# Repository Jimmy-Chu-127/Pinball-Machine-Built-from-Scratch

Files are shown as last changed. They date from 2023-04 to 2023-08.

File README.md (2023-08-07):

# Pinball Machine Built from Scratch

<!-- PROJECT LOGO -->
<br />
<div align="center">
  <a href="https://github.com/othneildrew/Best-README-Template">
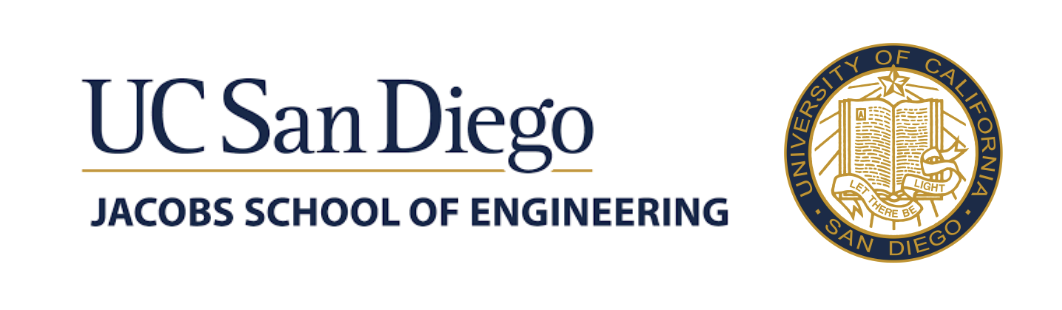
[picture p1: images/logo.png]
    
  </a>
  <h3 align="center">Pinball Machine Built from Scratch<br></h3>   
  <p align="center">
    Haozhang Chu, Yichen Yang <br>
  </p>
</div>

<!-- TABLE OF CONTENTS -->
<details>
  <summary><h2><b>Abstract</b><h2></summary>
    <li><a href="#finite-state-machine-design">Finite State Machine (FSM) Design</a></li>
    <li><a href="#whole-cad-assembly-view">Whole CAD Assembly View</a></li>
    <li><a href="#circuit-design">Circuit Design</a></li>
    <li><a href="#complete-physical-assembly">Complete Physical Assembly</a></li>
    <li>
      <a href="#subsystem-level-design">Subsystem Level Design</a>
      <ul>
        <li><a href="#ir-subsystem">IR subsystem</a></li>
        <li><a href="#flipper-subsystem">Flipper subsystem</a></li>
        <li><a href="#spinning-wheel-subsystem">Spinning wheel subsystem</a></li>
        <li><a href="#slingshot-subsystem">Slingshot subsystem</a></li>
      </ul>
    </li>
</details>

## Finite State Machine Design
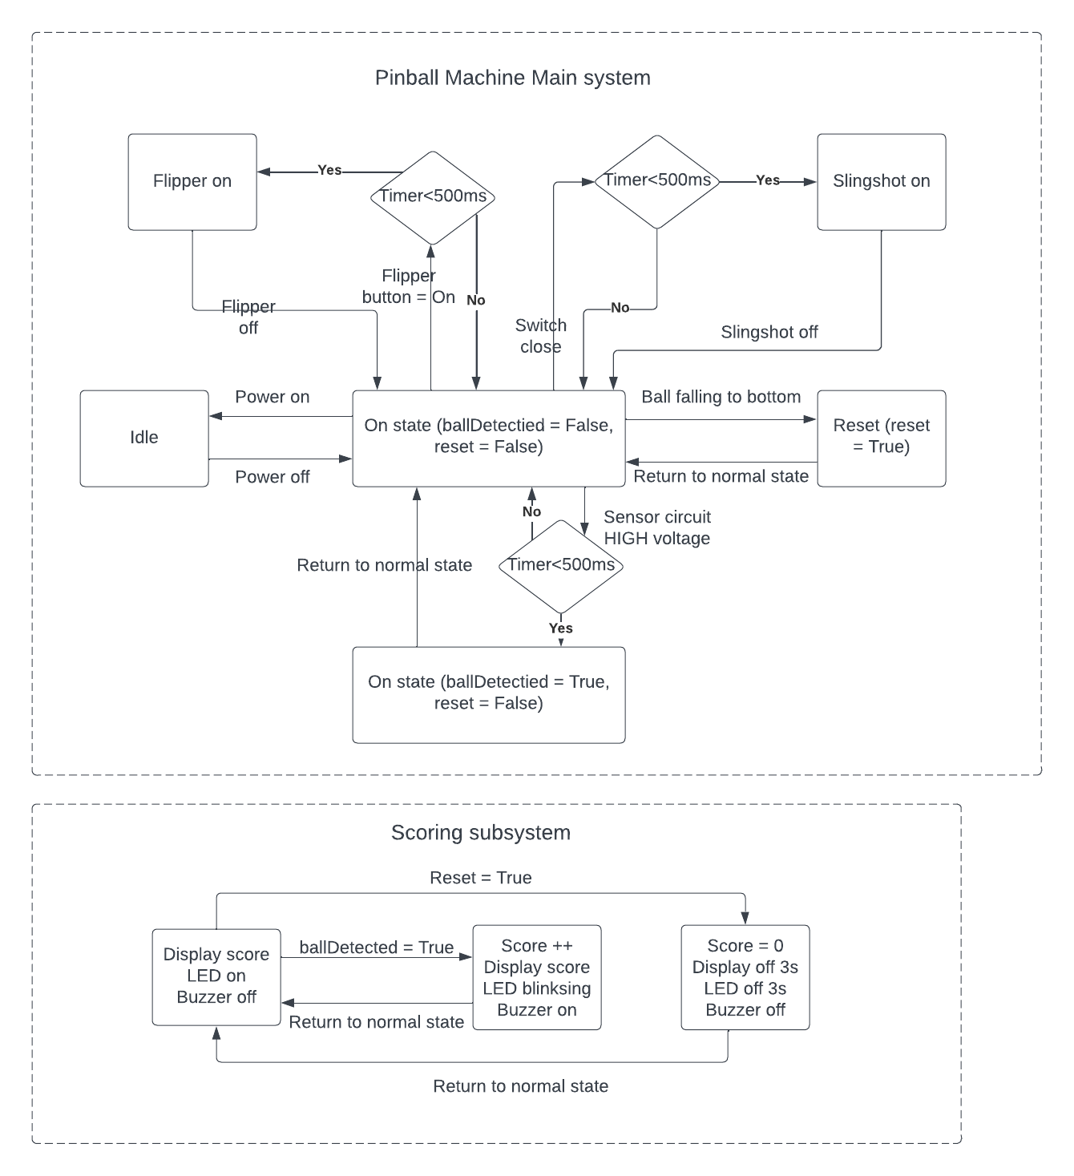
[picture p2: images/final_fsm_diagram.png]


## Whole CAD Assembly View
| Top view | Bottom View | Isometric view |
|:---:|:---:|:---:|
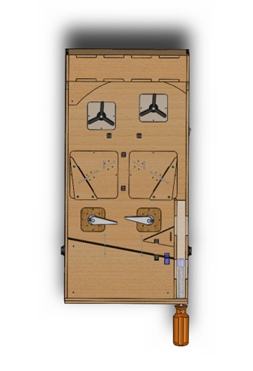
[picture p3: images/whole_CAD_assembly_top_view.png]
top view
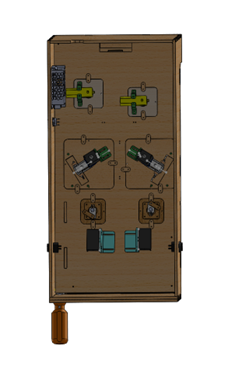
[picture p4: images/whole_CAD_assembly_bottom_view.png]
bottom view
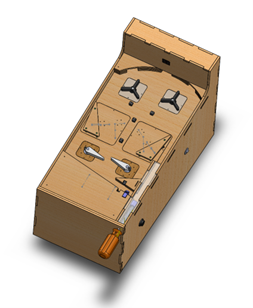
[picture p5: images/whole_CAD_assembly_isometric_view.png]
isometric view
|  |  |  |

## Circuit Design
| | |
|---|---|
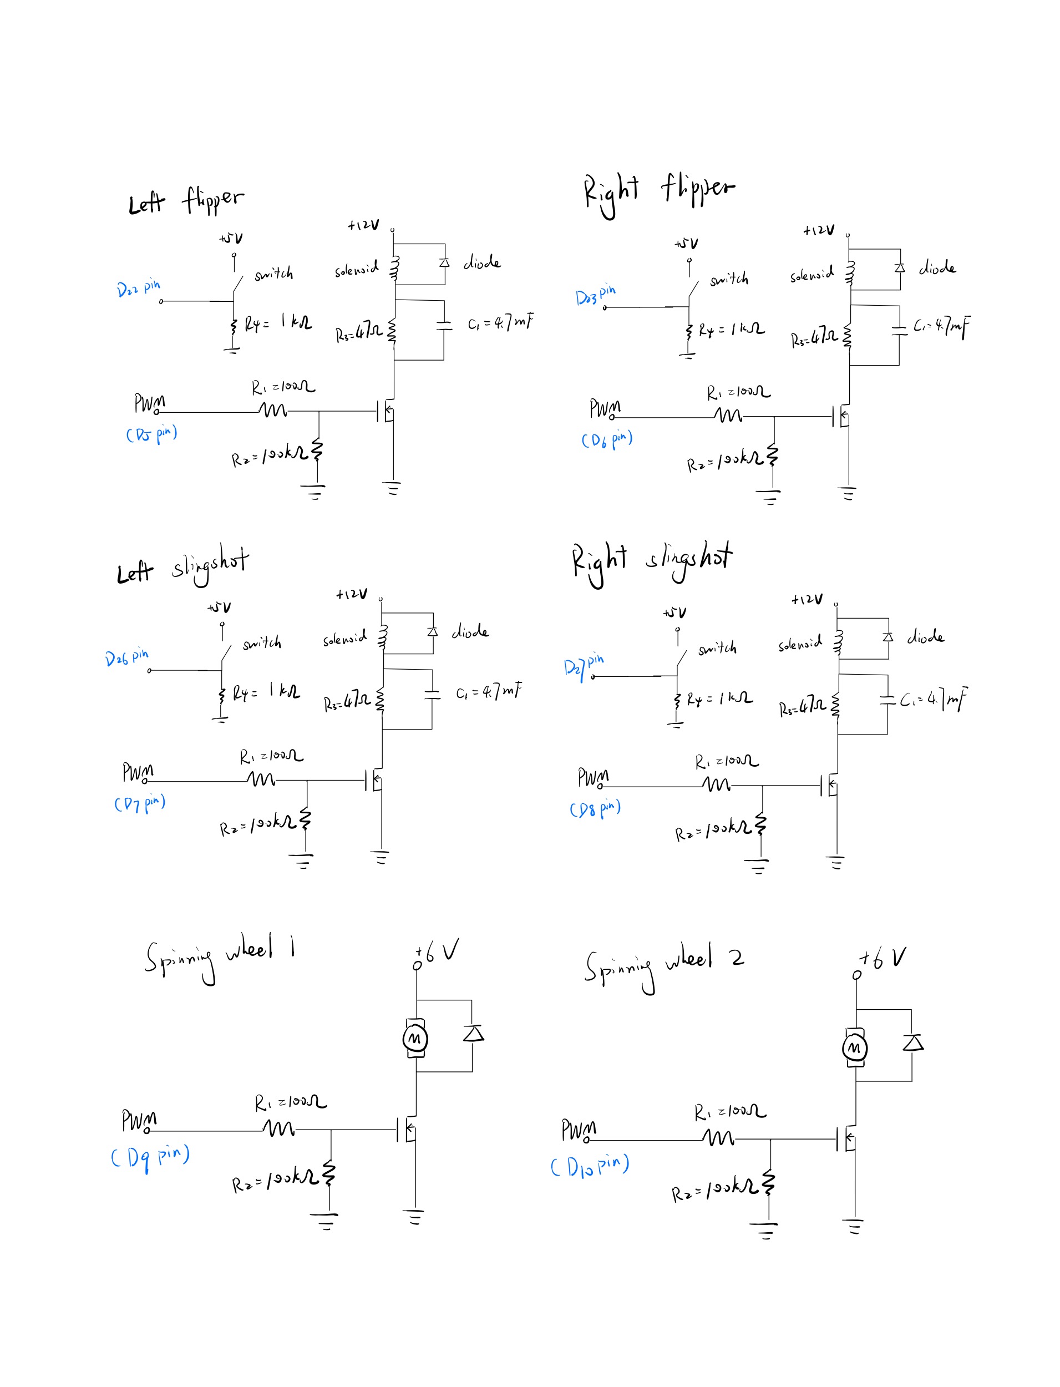
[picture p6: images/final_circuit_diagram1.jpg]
circuit1
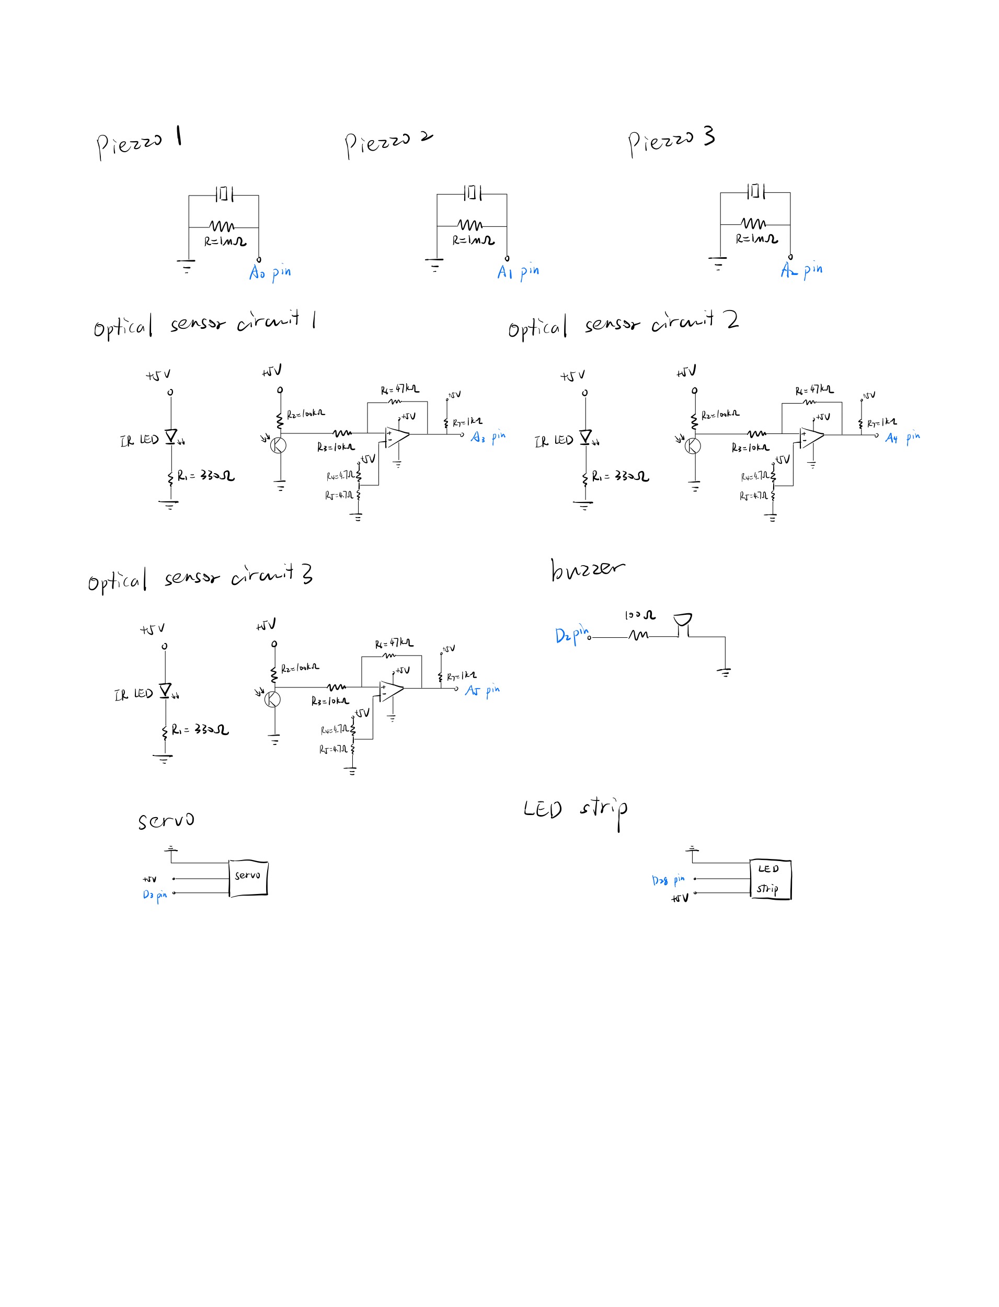
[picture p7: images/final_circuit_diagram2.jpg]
circuit1
|  |  |

## Complete Physical Assembly
| Top view | Bottom View | Isometric view |
|:---:|:---:|:---:|
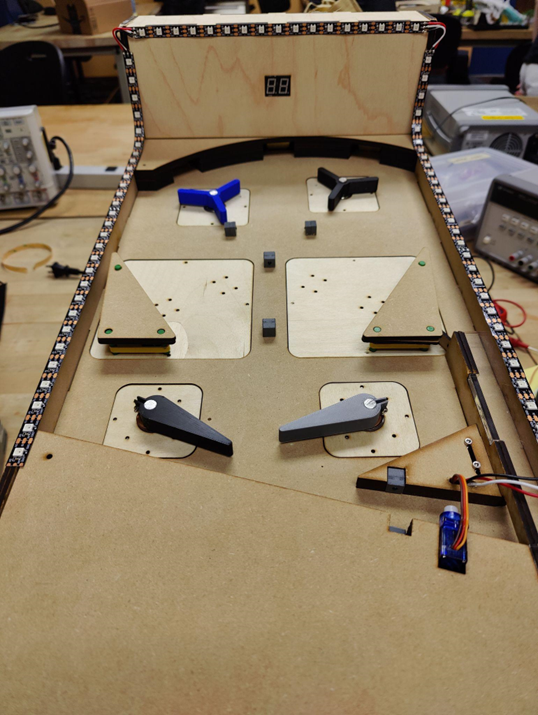
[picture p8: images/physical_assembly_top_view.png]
top view
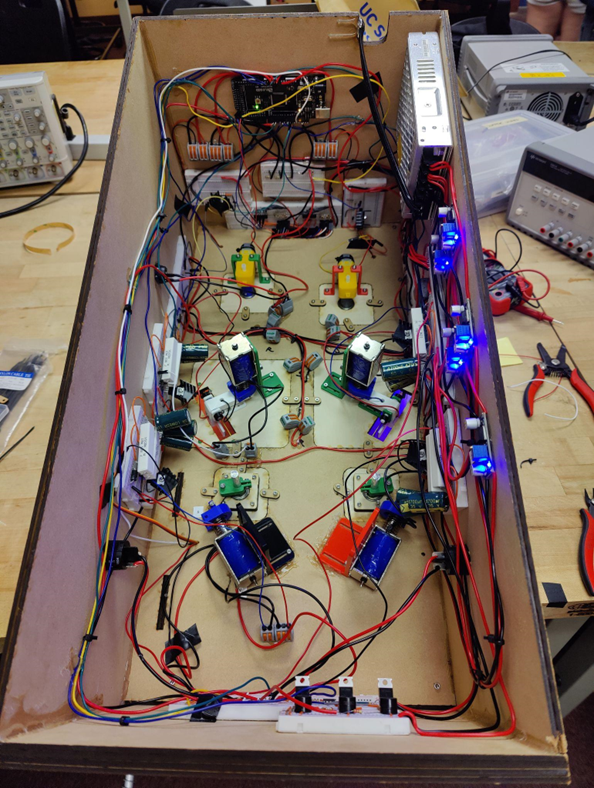
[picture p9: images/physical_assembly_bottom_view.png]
bottom view
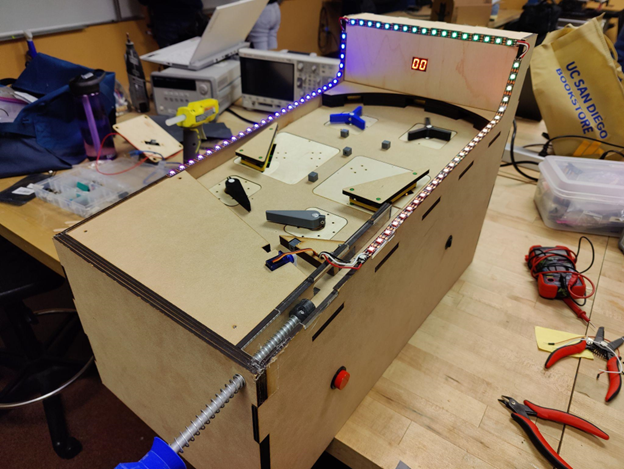
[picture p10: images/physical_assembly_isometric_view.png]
isometric view
|  |  |  |

## Subsystem Level Design

### IR subsystem
| Block Diagram | Circuit Diagram |
|:---:|:---:|
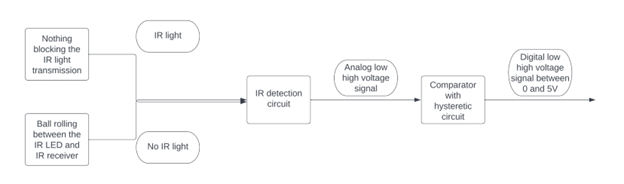
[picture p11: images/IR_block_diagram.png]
block diagram
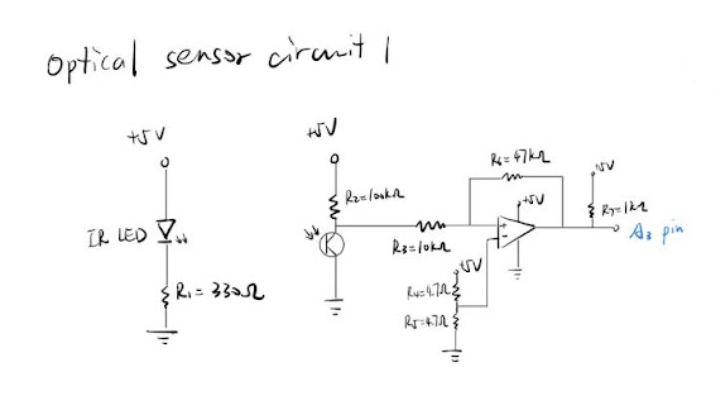
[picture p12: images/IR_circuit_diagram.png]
circuit diagram
|  |    |
| CAD Picture | Physical Picture |
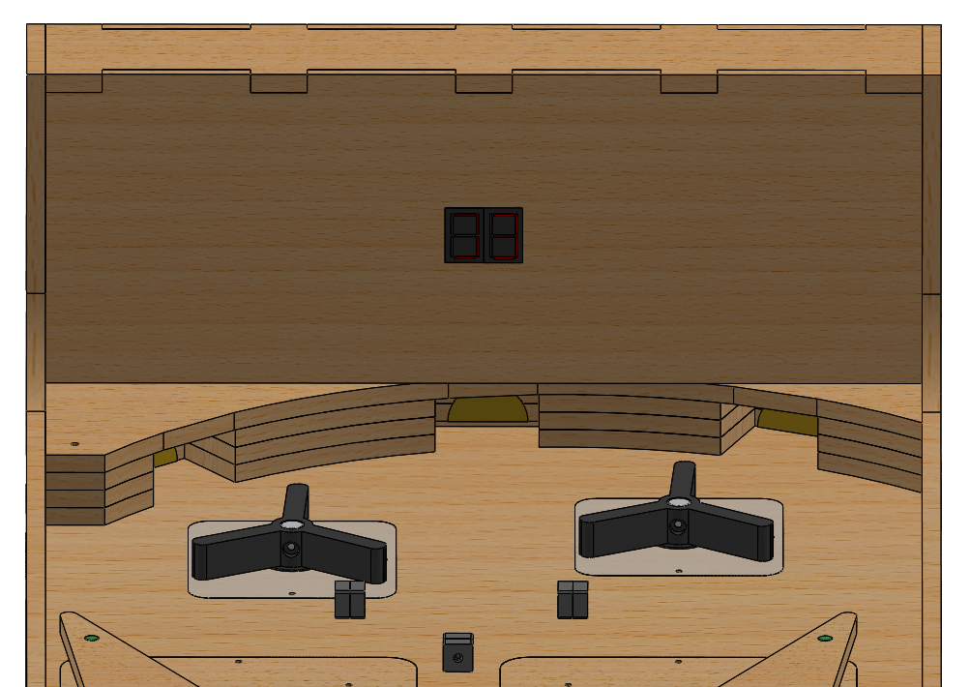
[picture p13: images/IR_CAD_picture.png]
CAD picture
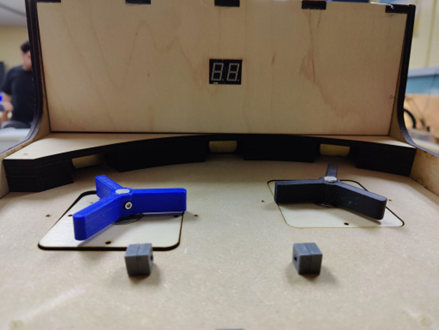
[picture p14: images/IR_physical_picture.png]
physical picture
|  |  |

### Flipper subsystem
| Block Diagram | Circuit Diagram |
|:---:|:---:|
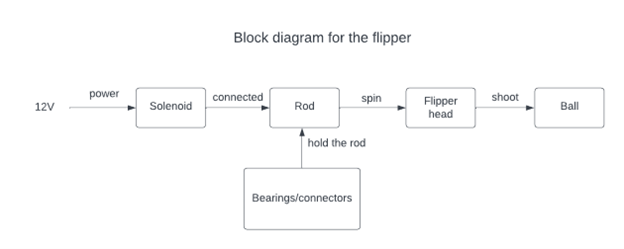
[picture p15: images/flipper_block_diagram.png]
block diagram
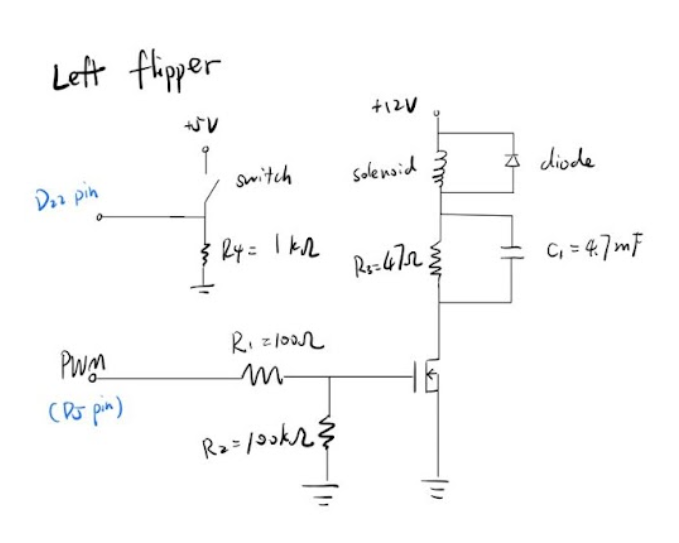
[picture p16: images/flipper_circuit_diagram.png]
circuit diagram
|  |    |
| CAD Picture | Physical Picture |
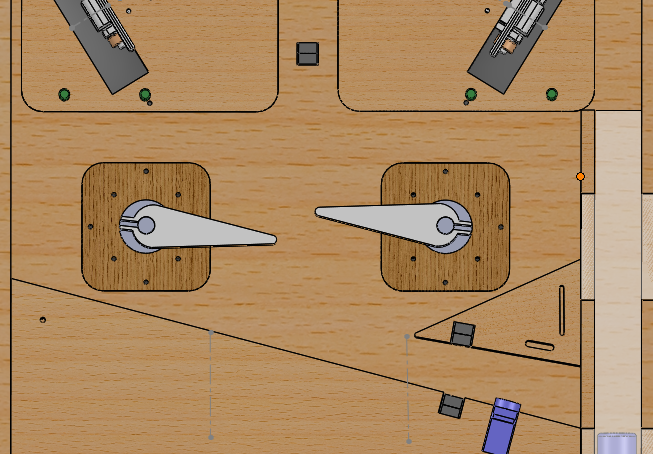
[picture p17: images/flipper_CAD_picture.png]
CAD picture
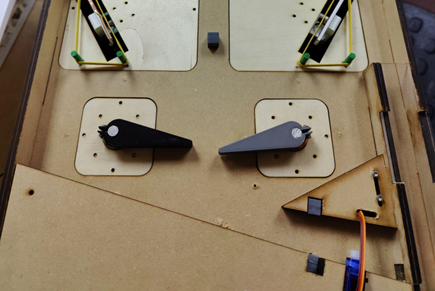
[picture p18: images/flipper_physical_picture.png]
physical picture
|  |  |

### Spinning wheel subsystem
| Block Diagram | Circuit Diagram |
|:---:|:---:|
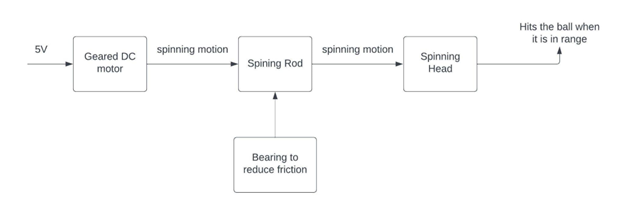
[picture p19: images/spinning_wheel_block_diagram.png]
block diagram
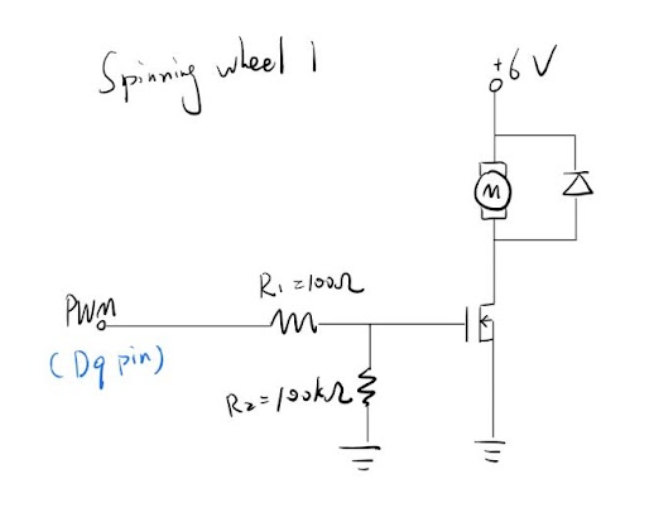
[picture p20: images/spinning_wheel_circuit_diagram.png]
circuit diagram
|  |    |
| CAD Picture | Physical Picture |
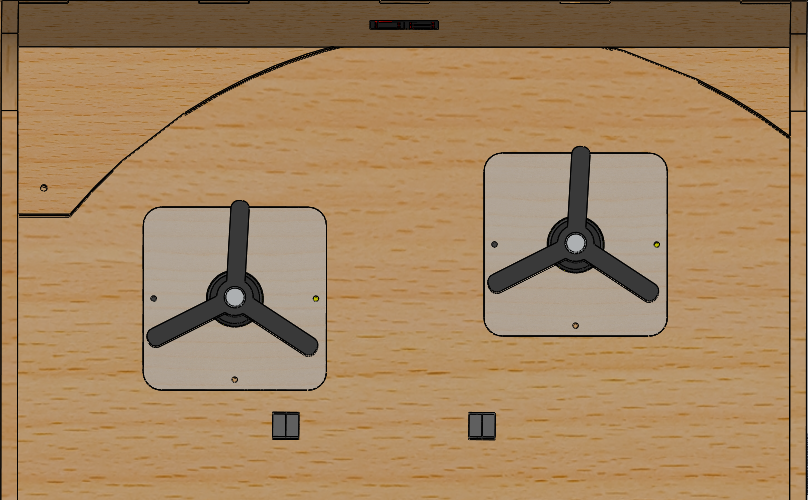
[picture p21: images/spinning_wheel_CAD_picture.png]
CAD picture
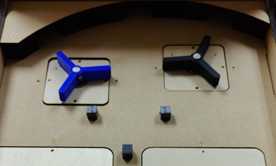
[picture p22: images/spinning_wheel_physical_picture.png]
physical picture
|  |  |

### Slingshot subsystem
| Block Diagram | Circuit Diagram |
|:---:|:---:|
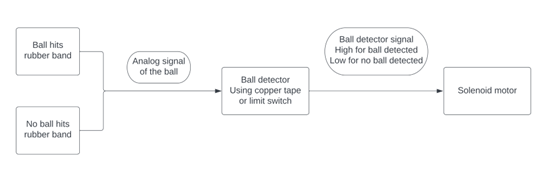
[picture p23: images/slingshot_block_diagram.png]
block diagram
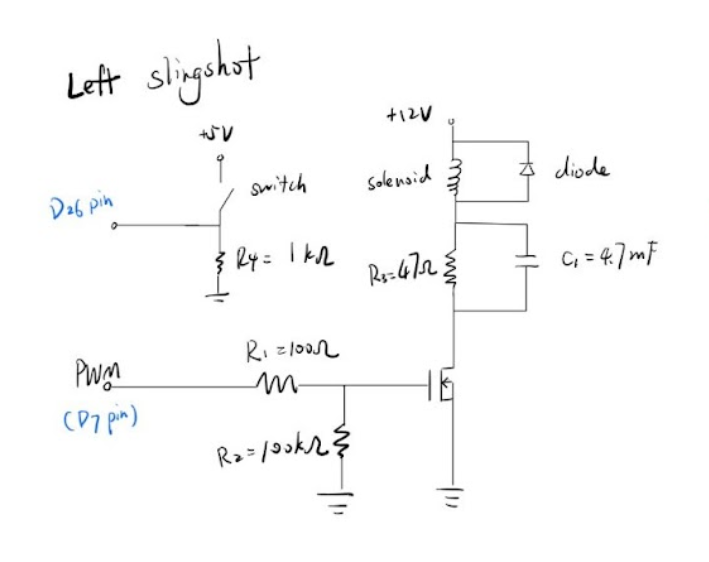
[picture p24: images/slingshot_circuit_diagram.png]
circuit diagram
|  |    |
| CAD Picture | Physical Picture |
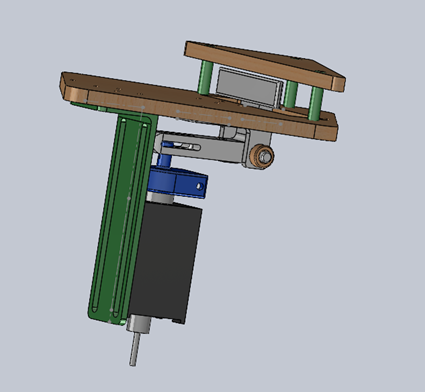
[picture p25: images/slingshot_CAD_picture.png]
CAD picture
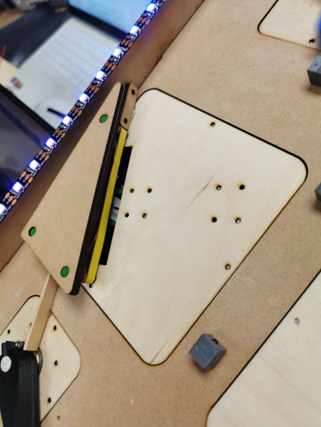
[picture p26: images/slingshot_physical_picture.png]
physical picture
|  |  |

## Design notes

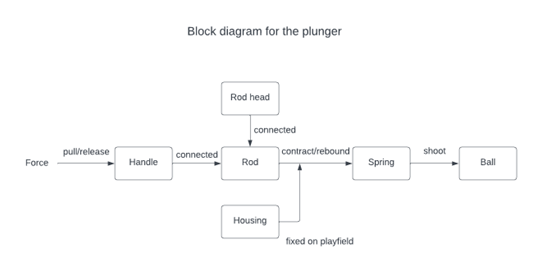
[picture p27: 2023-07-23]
images/plunger_block_diagram.png

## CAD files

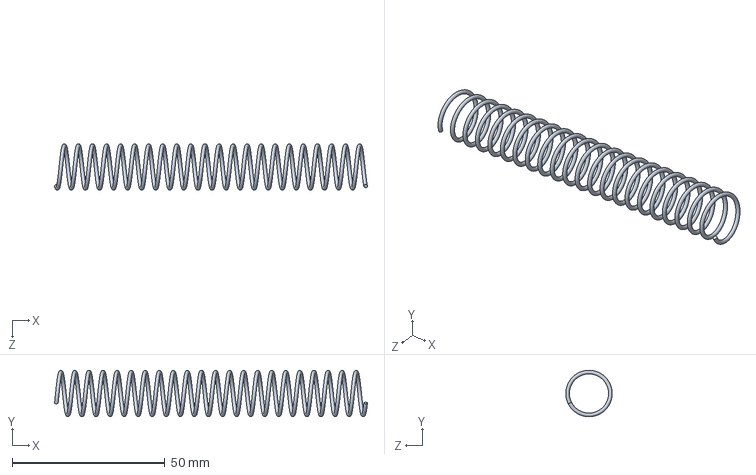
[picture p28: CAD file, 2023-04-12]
Module 1/ECE 115 Module 1 plunger assem.SLDASM
102.4 x 15.2 x 15.2 mm

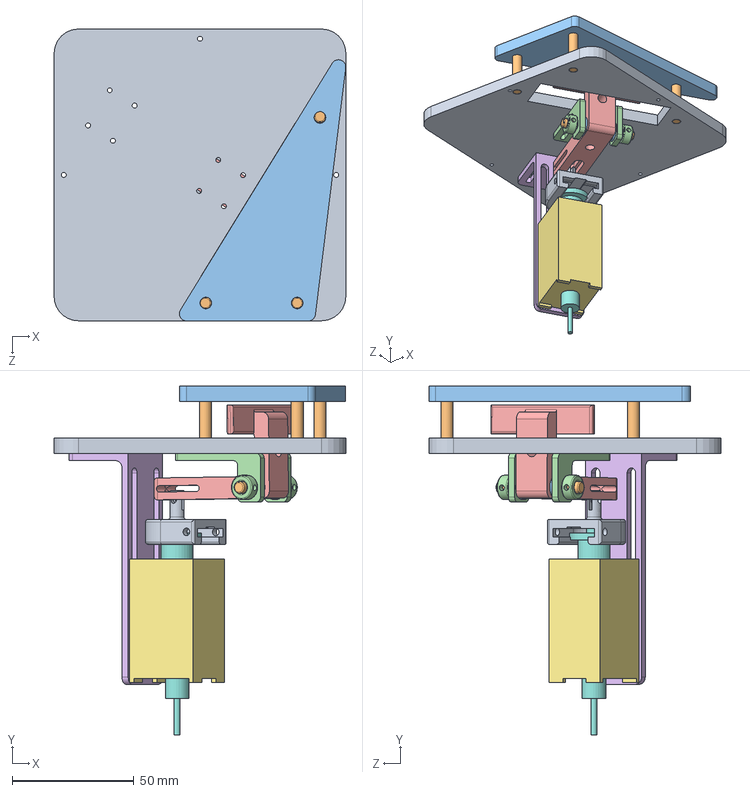
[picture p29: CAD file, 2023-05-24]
Module 2 revision/slingshot assem large.SLDASM
120.0 x 143.5 x 120.1 mm
slingshot testbed v3
slingshot support rod large x 3
slingshot cover large
slingshot arm holder large
slingshot arm large
slingshot solenoid holder vertical large
slingshot solenoid body large
slingshot solenoid rod large
slingshot solenoid tail connector with insert
slingshot arm rotate rod large
slingshot rotate washer x 2
slingshot rotate locker x 2

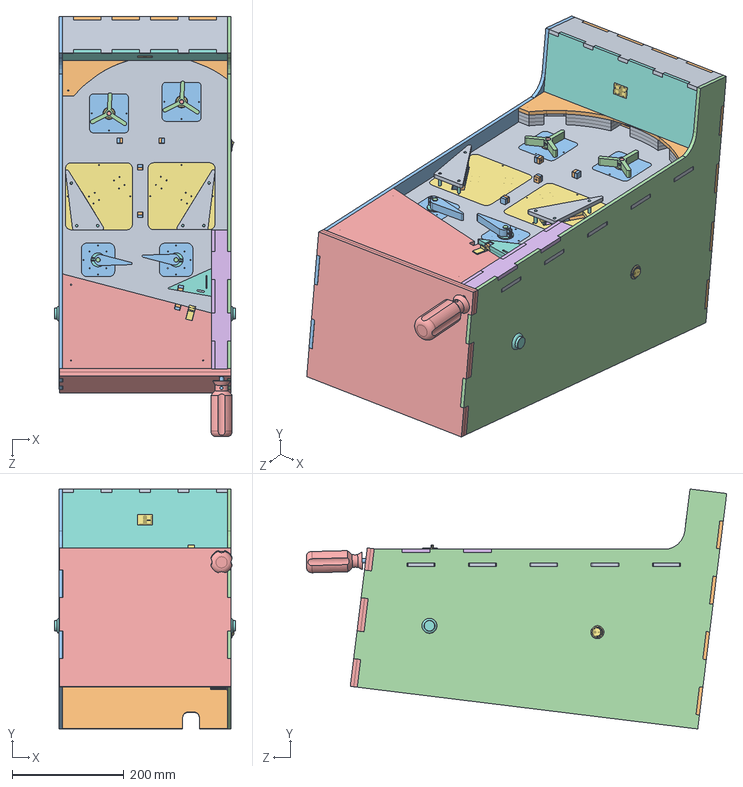
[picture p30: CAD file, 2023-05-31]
Module 4/final_assem.SLDASM
324.9 x 430.2 x 753.6 mm
playfield v2
surface_p1 x 3
flipper_part1 x 2
flipper_part2 x 2
flipper_part3 x 2
flipper_part4 x 2
flipper_bearing x 6
flipper_washer x 2
flipper_part5 x 2
flipper_part6 x 2
plane x 2
flipper_support_2 x 2
solenoid_holder2 x 2
slingshot solenoid body large x 4
servo
surface_p3 x 2
surface_p5 x 3
surface_p6
ECE 115 spin wheel testbed x 2
ECE 115 Playfield spinning wheel x 2
ECE 115 spin wheel rod x 2
ECE 115 spin wheel connector x 2
ECE 115 DC motor geared x 2
ECE 115 spin wheel holder side x 4
piezo_sensor x 3
IR mount 1 x 6
IR mount 2 x 6
surface_connector x 14
surface_p1_tap
surface_p2
7segment_display x 2
display_board1
display_board2
display_board3
surface_left_side_panel
surface_right_side_panel
surface_front_panel x 2
surface_plunger_cover
slingshot testbed v3 x 2
slingshot support rod large x 6
slingshot cover large x 2
slingshot arm holder large x 2
slingshot arm large x 2
slingshot solenoid holder vertical large x 2
slingshot solenoid rod large x 2
slingshot solenoid tail connector with insert x 2
slingshot arm rotate rod large x 2
slingshot rotate washer x 4
slingshot rotate locker x 4
plunger_head2
plunger_rod2
plunger_spring2
ECE 115 Module 1 plunger handle v2
SMPS SMALL_LRS-75-12.step
Rocker switch 3pin
flipper_button x 2

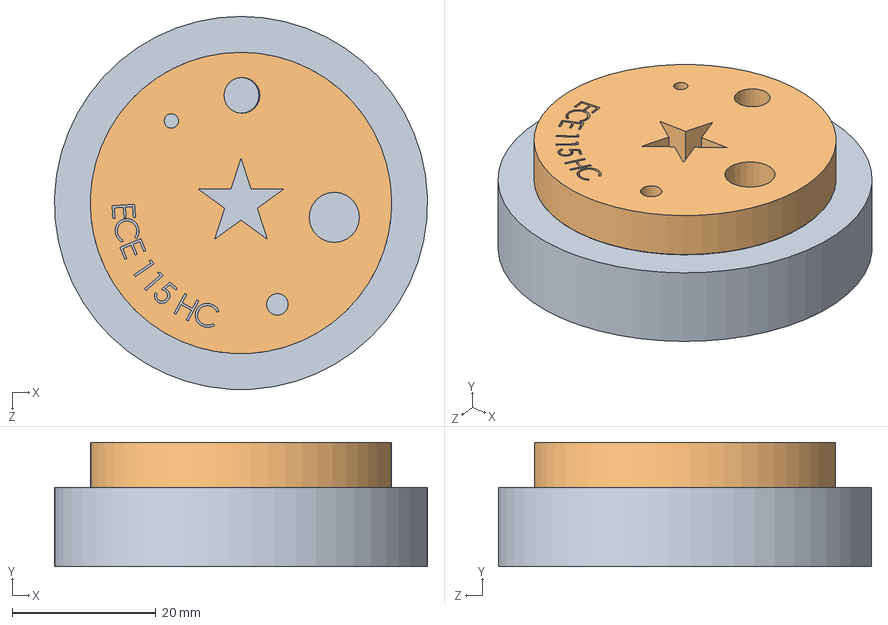
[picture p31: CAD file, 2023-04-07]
Module 1/HC/ECE 115 Module 1 assem HC.SLDASM
52.0 x 17.3 x 52.0 mm
ECE 115 3D printing Module 1 part1
ECE 115 3D printing Module 1 part2

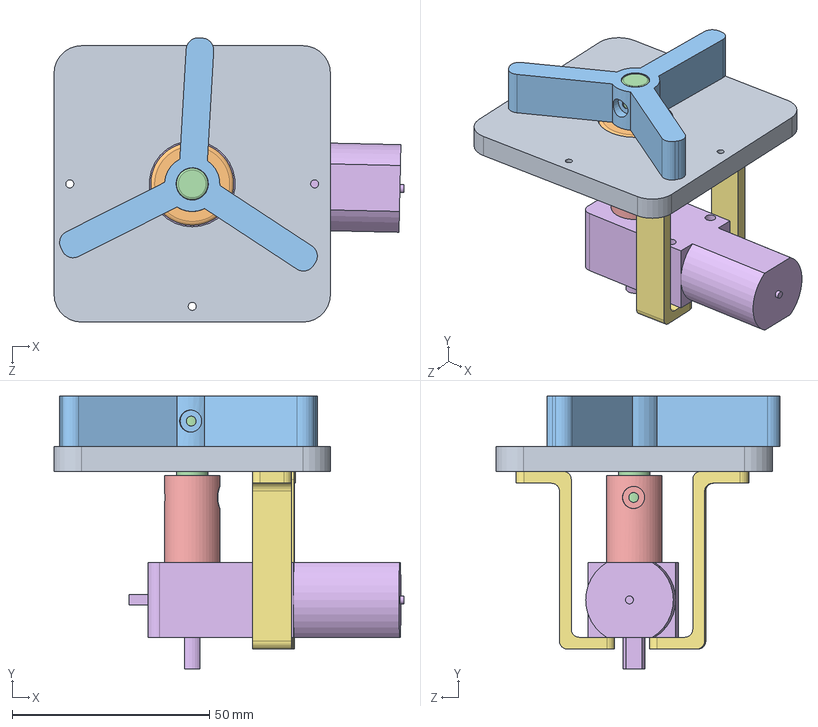
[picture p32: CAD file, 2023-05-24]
Module 2/ECE 115 spin wheel assembly.SLDASM
88.6 x 69.1 x 72.0 mm
ECE 115 spin wheel testbed
flipper_bearing
ECE 115 Playfield spinning wheel
ECE 115 spin wheel rod
ECE 115 spin wheel connector
ECE 115 DC motor geared
ECE 115 spin wheel holder side x 2

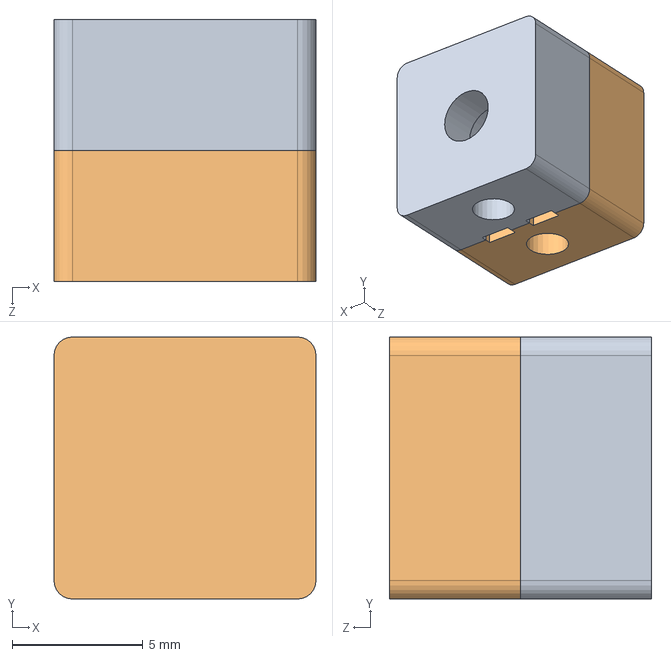
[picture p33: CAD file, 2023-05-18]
Module 3/IR mount assem.SLDASM
10.0 x 10.0 x 10.0 mm
IR mount 1
IR mount 2

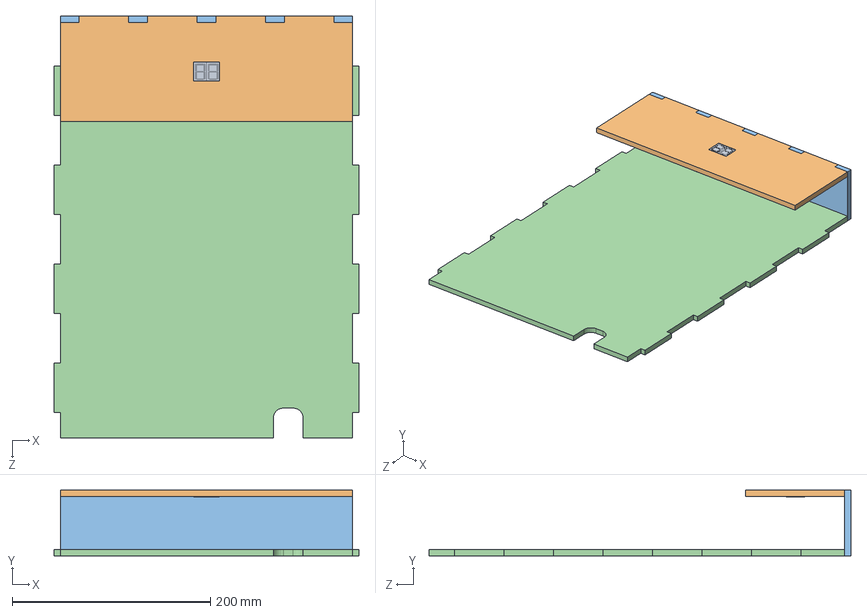
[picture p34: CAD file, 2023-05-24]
Module 4/display/display_assem.SLDASM
307.7 x 66.6 x 425.3 mm
7segment_display x 2
display_board1
display_board2
display_board3

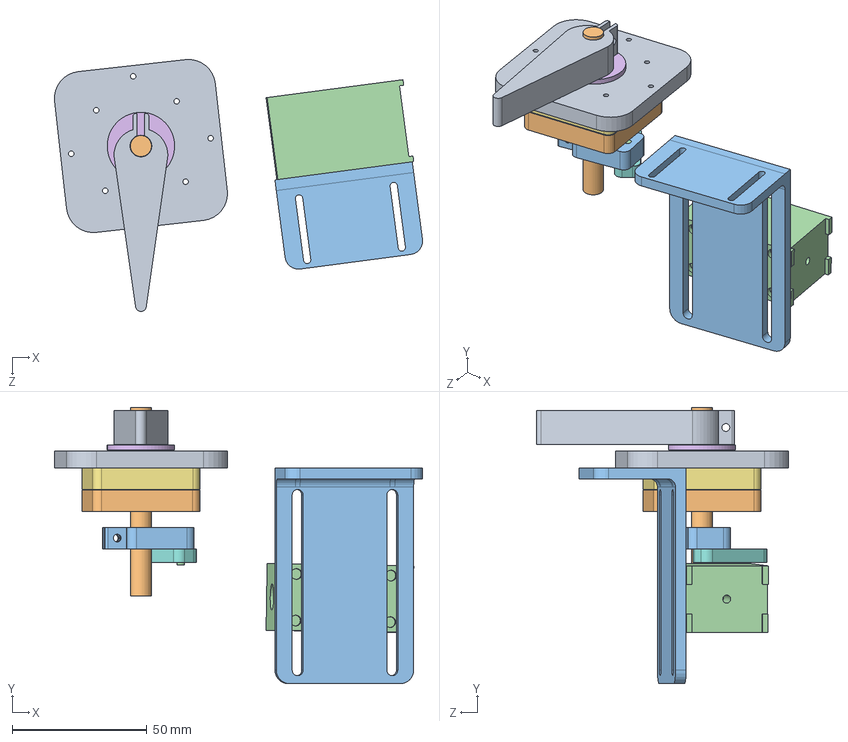
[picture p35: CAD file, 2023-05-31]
Module 4/flipper_update/flipper_assem1.SLDASM
136.5 x 102.5 x 93.4 mm
flipper_part1
flipper_part2
flipper_part3
flipper_part4
flipper_bearing x 2
flipper_washer
flipper_part5
flipper_part6
plane
flipper_support_2
solenoid_holder2
slingshot solenoid body large

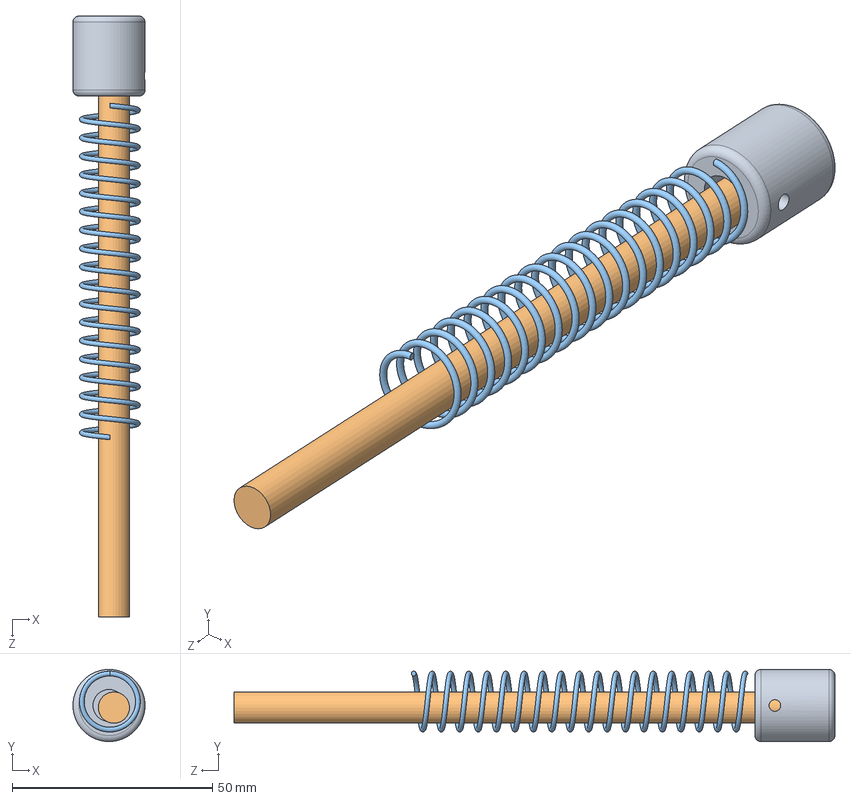
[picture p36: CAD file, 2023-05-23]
Module 4/plunger_update/plunger_assem2.SLDASM
18.0 x 18.0 x 150.0 mm
plunger_head2
plunger_rod2
plunger_spring2

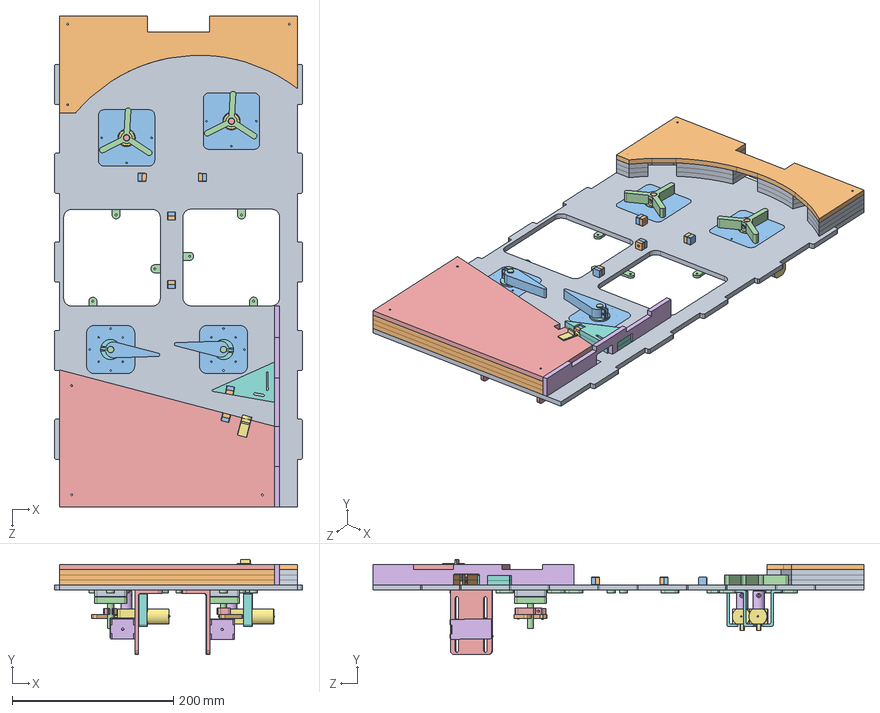
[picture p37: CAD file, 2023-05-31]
Module 4/surface_assembly.SLDASM
307.7 x 118.4 x 609.0 mm
playfield v2
surface_p1 x 3
flipper_part1 x 2
flipper_part2 x 2
flipper_part3 x 2
flipper_part4 x 2
flipper_bearing x 6
flipper_washer x 2
flipper_part5 x 2
flipper_part6 x 2
plane x 2
flipper_support_2 x 2
solenoid_holder2 x 2
slingshot solenoid body large x 2
servo
surface_p3 x 2
surface_p5 x 3
surface_p6
ECE 115 spin wheel testbed x 2
ECE 115 Playfield spinning wheel x 2
ECE 115 spin wheel rod x 2
ECE 115 spin wheel connector x 2
ECE 115 DC motor geared x 2
ECE 115 spin wheel holder side x 4
piezo_sensor x 3
IR mount 1 x 6
IR mount 2 x 6
surface_connector x 14
surface_p1_tap
surface_p2

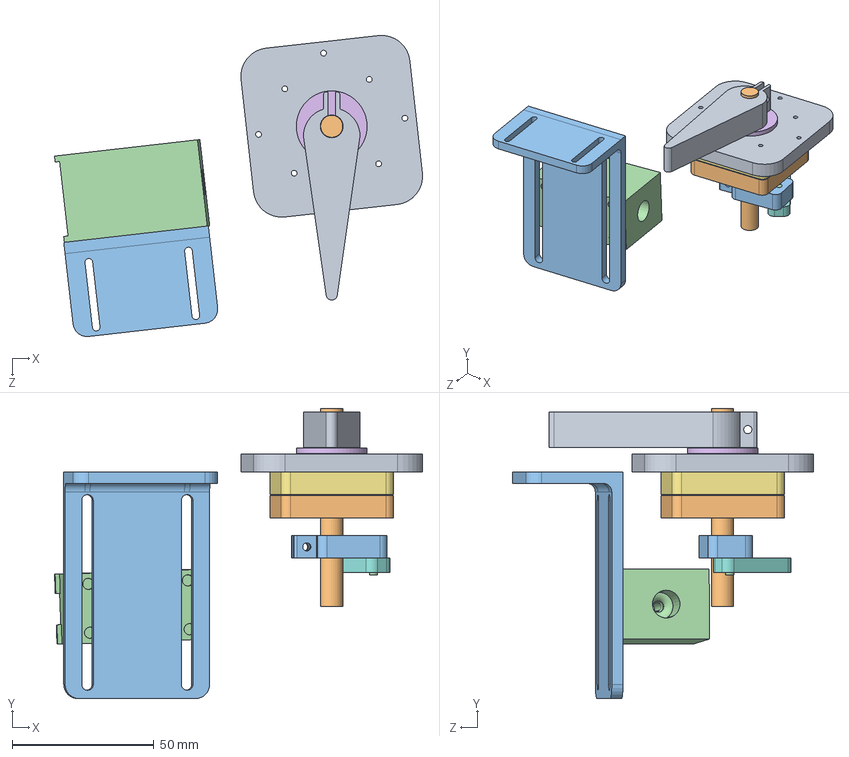
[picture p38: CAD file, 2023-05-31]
Module 4/flipper_update/flipper_assem2.SLDASM
129.9 x 102.5 x 106.3 mm
flipper_part1
flipper_part2
flipper_part3
flipper_part4
flipper_bearing x 2
flipper_washer
flipper_part5
flipper_part6
plane
flipper_support_2
solenoid_holder2
slingshot solenoid body large

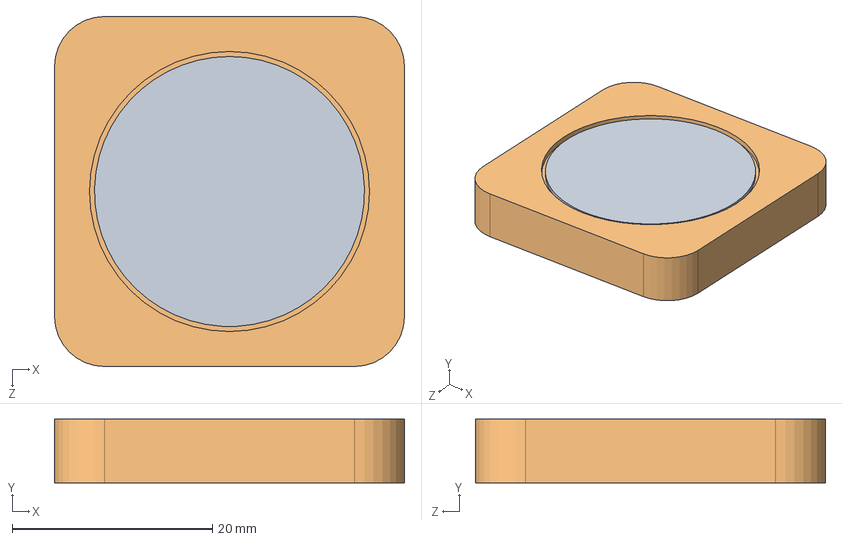
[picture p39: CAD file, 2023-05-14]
Module 4/piezo_cad/piezo_testbed_assem.SLDASM
35.0 x 6.35 x 35.0 mm
piezo_sensor
piezo_sensor_testbed

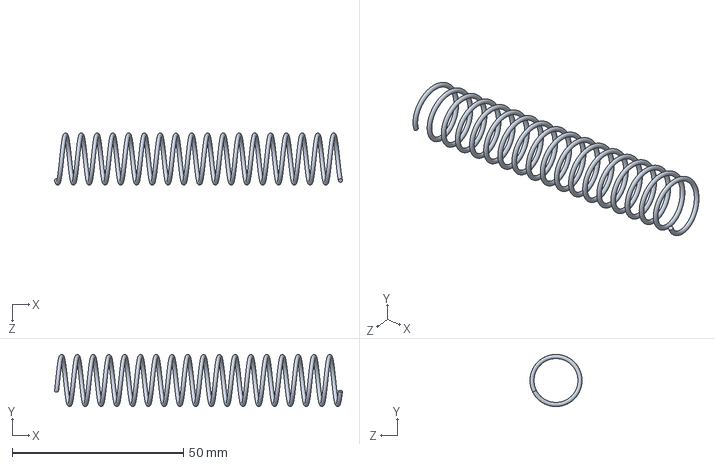
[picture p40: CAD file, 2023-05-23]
Module 4/plunger_update/ECE 115 Module 1 plunger assem.SLDASM
84.0 x 15.2 x 15.2 mm

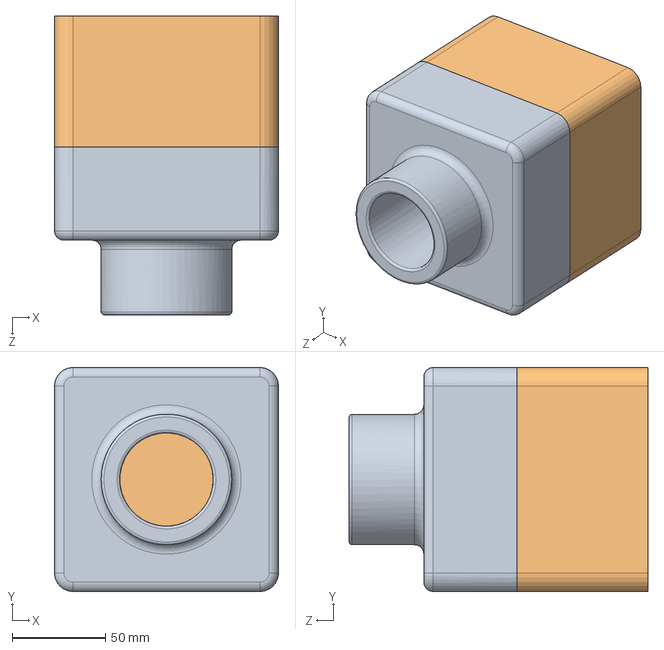
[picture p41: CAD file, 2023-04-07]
Module 1/HC/tutor.SLDASM
120.0 x 120.0 x 160.0 mm
Tutor1
Tutor2

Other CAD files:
Module 2 revision/slingshot assem large left.SLDASM
Module 2/slingshot assem.SLDASM
Module 1/plunger_assembly1_spring_head_rod.stl
Module 4/AL6M-M14G.SLDASM
3D printer - Laser cutting/5_21_print/3mf/ECE 115 Playfield spinning wheel.3mf
3D printer - Laser cutting/5_21_print/3mf/ECE 115 spin wheel connector.3mf
3D printer - Laser cutting/5_21_print/3mf/ECE 115 spin wheel holder side.3mf
3D printer - Laser cutting/5_21_print/stl/ECE 115 Playfield spinning wheel.STL
3D printer - Laser cutting/5_21_print/stl/ECE 115 spin wheel connector.STL
3D printer - Laser cutting/5_21_print/stl/ECE 115 spin wheel holder side.STL
3D printer - Laser cutting/5_24_cut/DXF/playfield v2.DXF
3D printer - Laser cutting/5_24_cut/DXF/slingshot testbed v3.DXF
3D printer - Laser cutting/5_24_cut/DXF/surface_connector.DXF
3D printer - Laser cutting/5_24_cut/DXF/surface_front_panel.DXF
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

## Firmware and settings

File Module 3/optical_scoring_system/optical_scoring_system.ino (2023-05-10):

const int dataPin = 4;
const int latchPin = 3; 
const int clkPin = 2;
const int displayOnePin = 9;
const int displayTwoPin = 10; 
//const int displayThreePin = 11;
//const int displayFourPin = 12; 

const int IRLedPin = 13;
const int IRRevPin = A0; 
int IRRevVal;
const int threshold = 600;
int score = 0; // player's score
int ballDetected = false; // indicator for pinball detection

long start_time = millis();
long display_time = millis();
long now_time;

const int buzzerPin = 7;
int buzzerEnabled = false;

const byte digits_anode[] = {
  B00000001, // 0
  B01001111, // 1
  B00010010, // 2
  B00000110, // 3
  B01001100, // 4
  B00100100, // 5
  B00100000, // 6
  B00001111, // 7
  B00000000, // 8
  B00000100  // 9
};

const byte digits_cathode[] = {
  B01111110, // 0
  B00110000, // 1
  B01101101, // 2
  B01111001, // 3
  B00110011, // 4
  B01011011, // 5
  B01011111, // 6
  B01110000, // 7
  B01111111, // 8
  B01111011  // 9
};

void setup() {
  pinMode(dataPin, OUTPUT);
  pinMode(latchPin, OUTPUT);
  pinMode(clkPin, OUTPUT);
  pinMode(displayOnePin, OUTPUT);
  pinMode(displayTwoPin, OUTPUT);
//  pinMode(displayThreePin, OUTPUT);
//  pinMode(displayFourPin, OUTPUT);

  pinMode(IRLedPin, OUTPUT);
  pinMode(IRRevPin, INPUT);

  pinMode(buzzerPin, OUTPUT);

  Serial.begin(9600);

}

void loop() {
  
  IRRevVal = analogRead(IRRevPin); // Read the voltage drop across the photodiode 

  ballDetection();
  
  //Serial.print("IRRevVal = ");
  //Serial.print(IRRevVal);
  //Serial.print("\t Score = ");
  //Serial.println(score);

  if (buzzerEnabled == true) {
    ringBuzzer(); // ring the buzzer
  }

  now_time = millis();
  displayScore(score); // Display the score on the two-digit 7-segment display

  if (now_time - start_time > 500 && ballDetected == true) {
    restartBallDetection(); // Reset the ball detection indicator
  }
}


void ballDetection(){
  // If the value exceed the threshold and the system did not detect a ball 
  // passing just before, increment the score by 1. Reset the timer.
  if (IRRevVal > threshold && ballDetected == false) {
    score++;
    ballDetected = true;
    start_time = millis();
    buzzerEnabled = true;
  }
}


void displayScore(int score) {
  int i = score / 10; // first digit
  int j = score % 10; // second digit

  //  Switch between the two digits every 10 milliseconds
  //Serial.println(now_time - display_time);
  if(now_time - display_time > 20){
    display_time = now_time;
  }else if(now_time - display_time < 10){
    digitalWrite(displayOnePin, HIGH);
    digitalWrite(displayTwoPin, LOW);
    digitalWrite(latchPin, LOW);
    shiftOut(dataPin, clkPin, LSBFIRST, digits_cathode[i]);
    digitalWrite(latchPin, HIGH);
    digitalWrite(displayOnePin, LOW);  
  }else{
    digitalWrite(displayTwoPin, HIGH);
    digitalWrite(latchPin, LOW);
    shiftOut(dataPin, clkPin, LSBFIRST, digits_cathode[j]);
    digitalWrite(latchPin, HIGH);
    digitalWrite(displayTwoPin, LOW);  
  }
}


void restartBallDetection() {
  // Reset the indicator
    ballDetected = false;
    buzzerEnabled = false;
    start_time = now_time;
}


void ringBuzzer() {
  // Ring the buzzer for 0.2s
  if (now_time - start_time < 200){
    tone(buzzerPin, 1000);
  }else{
    noTone(buzzerPin);
  }
}

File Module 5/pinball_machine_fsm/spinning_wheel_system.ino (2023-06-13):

const int wheel1Pin = 9; 
const int wheel2Pin = 10;
// const int pot1Pin = A0;
// int pot1Val;

// Set up pins
void setupSpinningWheel() {
  pinMode(wheel1Pin, OUTPUT);
  pinMode(wheel2Pin, OUTPUT);
}

// Change the speed of the wheel according to the potentiometer reading
void setWheelSpeed() {
//  pot1Val = analogRead(pot1Pin);
//  int motorSpeed = map(pot1Val, 0, 1023, 0, 255);
//  analogWrite(wheel1Pin, motorSpeed);
  analogWrite(wheel1Pin, 255);
  analogWrite(wheel2Pin, 255);
}

void WheelOFF(){
  analogWrite(wheel1Pin, 0);
  analogWrite(wheel2Pin, 0);
}

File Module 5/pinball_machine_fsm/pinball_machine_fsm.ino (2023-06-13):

// Set up timers
long nowTime;

long flipper1Time = millis();
long flipper2Time = millis(); 

long slingshot1Time = millis();
long slingshot2Time = millis(); 

long piezoTime = millis();
 
long displayTime = millis();
long ir1Time = millis();
long ir2Time = millis();
long ir3Time = millis();

// Define states
enum FSMState {
  ON,
  OFF,
  SCORE,
  RESET
};
FSMState currentState;

int ledState;
int buzzerState;
int servoState;
int score = 0;
int roundCnt = 3;

int slingshot1State;
int slingshot2State;

// Define functions
//void displayCurrentScore(){
//  if(nowTime - displayTime > 20){
//    displayTime = nowTime;
//  }else if(nowTime - displayTime < 10){
//    setDisplay(1, score / 10);
//  }else{
//    setDisplay(2, score % 10);
//  }
//}

void setup() {
  Serial.begin(9600);
  setupDisplay();
  setupOpticalSensorSystem();
  setupPiezoSensorSystem();
  setupFlipper();
  setupSlingshot();
  setupSpinningWheel();
  setupBuzzer();
  setupLED();
  setupServo();
  setupPower();

  currentState = OFF;
}

void loop() {
  //Serial.println(2);
  nowTime = millis();
  if (powerButtonOn() == HIGH && currentState == OFF){
    currentState = ON;
  }else if(powerButtonOn() == LOW){
    currentState = OFF;
  }
  
  switch (currentState) {
    case OFF:
      ledOFF();
      WheelOFF();
      return;   
    case ON:
      // Check the optical scoring system and the corresponding timer
      if (ir1BallDetected() == HIGH && nowTime - ir1Time > 300){
        //Serial.println("IR1 detected");
        currentState = SCORE;
        ir1Time = nowTime;
      }
      
      if (ir2BallDetected() == HIGH && nowTime - ir2Time > 300){
        //Serial.println("IR2 detected");
        currentState = SCORE;
        ir2Time = nowTime;
      }

      // Check the piezo sensor system and the corresponding timer
      if (piezoBallDetected() == HIGH && nowTime - piezoTime > 1000){
        currentState = SCORE;
        piezoTime = nowTime;
      }

      // Check flipper1 system and the corresponding timer
//      if (flipper1Button() == HIGH && nowTime - flipper1Time > 300){
//        flipper1Flip();
//        flipper1Time = nowTime;
//      }
//        flipper1Button();
//        flipper2Button();
      if (flipper1Button() == HIGH){
        flipper1On();
      }else{
        flipper1Off();
      }

      // Check flipper2 system and the corresponding timer
//      if (flipper2Button() == HIGH && nowTime - flipper2Time > 300){
//        flipper2Flip();
//        flipper2Time = nowTime;
//      }

      if (flipper2Button() == HIGH){
        flipper2On();
      }else{
        flipper2Off();
      }

      // Check slingshot1 system and the corresponding timer
      if (slingshot1Switch() == HIGH && nowTime - slingshot1Time > 300){
        slingshot1Time = nowTime;
        slingshot1State = 1;
      }else{
        slingshot1State = 0;
      }
      
//      if (slingshot1Switch == HIGH){
//        slingshot1On();
//      }else{
//        slingshot1Off();
//      }

      // Check slingshot2 system and the corresponding timer
      if (slingshot2Switch() == HIGH && nowTime - slingshot2Time > 300){
        slingshot2Time = nowTime;
        slingshot2State = 1;
      }else{
        slingshot2State = 0;
      }
      
//      if (slingshot2Switch == HIGH){
//        slingshot2On();
//      }else{
//        slingshot2Off();
//      }      

      // Check the resetting system and the corresponding timer
      if (ir3BallDetected() == HIGH && nowTime - ir3Time > 5000 ){
          //Serial.println("Detected");
          roundCnt = roundCnt-1;
          if(roundCnt == 0){
            currentState = RESET;
            buzzerState = 2; // ring for 1.5s
            servoState = 1; // round lost state
            ledState = 2;
          }else{
            currentState = ON;
            buzzerState = 1; // ring for 0.3s
            servoState = 1; // round lost state
            ledState = 2;
          }
        ir3Time = nowTime;
      }else{
        buzzerState = 0;
        servoState = 0;
        ledState = 0;
      }
    
      break;

    case SCORE:
      // Score increases, LEDs blink, buzzer rings
      score++; 
      currentState = ON; // return to ON state

      ledState = 0;
      buzzerState = 3; // ring for 0.1s
      servoState = 0;
      ledState = 3;
      
      break;

    case RESET:
      score = 0;
      roundCnt = 3; // reset round count
      currentState = ON; // return to ON state

      ledState = 2;
      buzzerState = 2; // ring for 1.5s
      servoState = 1; // round lost state
      
      break;
  }

//  displayCurrentScore();
//  Serial.println(score);
//  if(servoState == 1){
//  Serial.println(servoState);
//  }
  slingshot1Shot(slingshot1State, nowTime);
  slingshot2Shot(slingshot2State, nowTime);
  
  setDisplay(score);
  //delay(10);
  setWheelSpeed();
  ledSystem(ledState, nowTime);
  buzzerSystem(buzzerState, nowTime);
  servoSystem(servoState, nowTime);
  //Serial.println(roundCnt);
  //Serial.println("-------------------------------");
}

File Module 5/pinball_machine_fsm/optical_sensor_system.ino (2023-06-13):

const int irLED1Pin = 11;
const int irRev1Pin = A3; 
int ir1Val;

const int irLED2Pin = 12;
const int irRev2Pin = A4; 
int ir2Val;

const int irLED3Pin = 13;
const int irRev3Pin = A5; 
int ir3Val;

const int threshold = 300;

// Set up pins
void setupOpticalSensorSystem() {
  pinMode(irLED1Pin, OUTPUT);
  pinMode(irRev1Pin, INPUT);
  pinMode(irLED2Pin, OUTPUT);
  pinMode(irRev2Pin, INPUT);
}

// Detect if the pinball passes through optical sensor circuit 1
int ir1BallDetected() {
  ir1Val = analogRead(irRev1Pin);
//  Serial.print(ir1Val);
  if (ir1Val <= threshold){
    return LOW;
  }
  return HIGH;
}

// Detect if the pinball passes through optical sensor circuit 2
int ir2BallDetected() {
  ir2Val = analogRead(irRev2Pin);
//  Serial.print("  ");
//  Serial.print(ir2Val);
//  Serial.print("  ");
  if (ir2Val <= threshold){
    return LOW;
  }
  return HIGH;
}

// Detect if the pinball passes through optical sensor circuit 3
int ir3BallDetected() {
  ir3Val = analogRead(irRev3Pin);
  //Serial.println(ir3Val);
  if (ir3Val <= 300){
    return LOW;
  }
  return HIGH;
}

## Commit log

2023-04-07 Prelab parts
    [ECE 115 Module 1 assem HC.SLDASM, ECE 115 Module 1 part1 HC.SLDPRT, ECE 115 Module 1 part2 HC.SLDPRT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]
2023-04-08 plunger update
    [plunger_assembly1_spring_head_rod.stl, plunger_head.sldprt, plunger_rod.sldprt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]
2023-04-09 spring update
    [plunger_spring2.SLDPRT]
2023-04-09 my parts and assembly
    [ECE 115 Module 1 plunger assem.SLDASM, ECE 115 Module 1 plunger handle v2.SLDPRT, ECE 115 Module 1 plunger testbed base HC.SLDPRT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]
2023-04-12 assem update + side update
    [ECE 115 Module 1 plunger assem.SLDASM, ECE 115 Module 1 plunger testbed side HC v2.SLDPRT]
2023-04-19 Create solenoid body.SLDPRT
    [solenoid body.SLDPRT]
2023-04-20 flipper updated
    [flipper_assem1.SLDASM, flipper_bearing.SLDPRT, flipper_part1.SLDPRT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]
2023-04-21 3.3.5 Servo/DC motor files
    [ECE 115 DC motor geared.SLDPRT, ECE 115 Playfield spinning wheel.SLDPRT, ECE 115 spin wheel assembly.SLDASM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]
2023-04-21 3.3.5 Servo/DC motor files v2
    [ECE 115 DC motor geared.SLDPRT, ECE 115 Playfield spinning wheel.SLDPRT, ECE 115 spin wheel assembly.SLDASM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]
2023-04-21 testbed update with svg files
    [ECE 115 spin wheel testbed.DXF]
2023-04-21 add in fillet
    [ECE 115 spin wheel assembly.SLDASM, ECE 115 spin wheel holder side.SLDPRT]
2023-04-21 slingshot update
    [slingshot arm holder.SLDPRT, slingshot arm.SLDPRT, slingshot limit switch.SLDPRT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]
2023-04-25 slingshot updates
    [ECE 115 spin wheel testbed.DXF, ECE 115 spin wheel testbed.SLDPRT, slingshot assem.SLDASM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]
2023-04-26 flipper assem update
    [flipper_assem1.SLDASM, solenoid body.SLDPRT, solenoid_holder.SLDPRT]
2023-04-26 move loc of selenoid body
    [solenoid body.SLDPRT]
2023-05-07 version 1
    [IR mount 1.SLDPRT, IR mount 1.STL, IR mount 2.SLDPRT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]
2023-05-07 version 2
    [IR mount 1.SLDPRT, IR mount 1.STL, IR mount 2.SLDPRT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]
2023-05-08 version 3
    [IR mount 1.SLDPRT, IR mount 1.STL, IR mount 2.SLDPRT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]
2023-05-09 material update + minor update
    [IR mount 1.SLDPRT, IR mount 2.SLDPRT, IR mount assem.SLDASM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]
2023-05-09 Update IR mount 2.SLDPRT
    [IR mount 2.SLDPRT]
2023-05-12 larger slingshot mod
    [slingshot arm holder large.SLDPRT, slingshot arm holder.SLDPRT, slingshot arm large.SLDPRT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]
2023-05-12 smaller testbed + hole size adjustment
    [IR mount testbed.SLDPRT, slingshot assem large.SLDASM, slingshot testbed v3.SLDPRT]
2023-05-12 Folder organization + update
    [slingshot arm holder large.SLDPRT, slingshot arm large.SLDPRT, slingshot arm rotate rod large.SLDPRT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]
2023-05-13 Update ECE 115 spin wheel assembly.SLDASM
    [ECE 115 spin wheel assembly.SLDASM]
2023-05-17 cad updated
    [IR mount assem.SLDASM, playfield.SLDPRT, servo.SLDPRT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]
2023-05-18 5/18 update
    [playfield.SLDPRT, surface_assembly.SLDASM, surface_p1.SLDPRT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]
2023-05-21 5/20 update
    [7segment_display.SLDPRT, flipper_assem1.SLDASM, flipper_assem2.SLDASM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]
2023-05-21 whole assembly update
    [surface_assembly.SLDASM, surface_left_side_panel.SLDPRT, surface_p1.SLDPRT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]
2023-05-21 edge fillet update
    [playfield.SLDPRT, surface_assembly.SLDASM]
2023-05-21 Create playfield v2.SLDPRT
    [playfield v2.SLDPRT]
2023-05-22 surface assembly update
    [playfield v2.SLDPRT, playfield.SLDPRT, surface_assembly.SLDASM]
2023-05-22 flipper and display board update
    [7segment_display.SLDPRT, display_assem.SLDASM, display_board1.SLDPRT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]
2023-05-22 add final assem
    [final_assem.SLDASM, surface_assembly.SLDASM]
2023-05-22 3D printing file update
    [ECE 115 Playfield spinning wheel.3mf, ECE 115 Playfield spinning wheel.STL, ECE 115 spin wheel connector.3mf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]
2023-05-22 deleting the side panel
    [surface_assembly.SLDASM]
2023-05-22 side panel size adjustment
    [final_assem.SLDASM, surface_left_side_panel.SLDPRT, surface_right_side_panel.SLDPRT]
2023-05-22 Plunger update/Side board update/front panel update/parts minor adjustments
    [final_assem.SLDASM, playfield v2.SLDPRT, surface_assembly.SLDASM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]
2023-05-23 most recent
    [final_assem.SLDASM, surface_assembly.SLDASM]
2023-05-23 final assem update
    [final_assem.SLDASM, playfield v2.SLDPRT, surface_assembly.SLDASM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]
2023-05-23 Slingshot system update
    Additional washer, Additional collars, updated assembly
    [slingshot arm holder large.SLDPRT, slingshot arm large.SLDPRT, slingshot arm rotate rod large.SLDPRT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]
2023-05-23 display update
    [display_assem.SLDASM, display_board3.SLDPRT]
2023-05-23 5/23 update 1
    [ECE 115 Module 1 plunger assem.SLDASM, ECE 115 Module 1 plunger handle v2.SLDPRT, ECE 115 Module 1 plunger testbed base HC.SLDPRT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]
2023-05-23 slingshot left assembly update
    [slingshot assem large left.SLDASM, slingshot assem large.SLDASM, slingshot testbed v3.SLDPRT]
2023-05-23 playfield hold update
    [final_assem.SLDASM, playfield v2.SLDPRT, surface_assembly.SLDASM]
2023-05-23 plunger location update
    [final_assem.SLDASM, plunger_assem2.SLDASM, plunger_head2.SLDPRT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]
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2023-05-24 update for wiring to go through from the display to the Arduino
    [display_assem.SLDASM, final_assem.SLDASM, playfield v2.SLDPRT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]
2023-05-24 adding button to the whole assem
    [flipper_button.SLDPRT, slingshot arm rotate rod large.STL, slingshot rotate washer.SLDPRT]
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2023-05-24 laser cut 3d print files update
    [final_assem.SLDASM, playfield v2.DXF, slingshot testbed v3.DXF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]
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2023-07-23 Fixing embedded image for whole CAD assembly
2023-07-23 Fixing embedded images for physical assembly
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
